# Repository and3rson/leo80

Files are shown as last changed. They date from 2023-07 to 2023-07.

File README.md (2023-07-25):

# leo80
Z80-based single-board computer

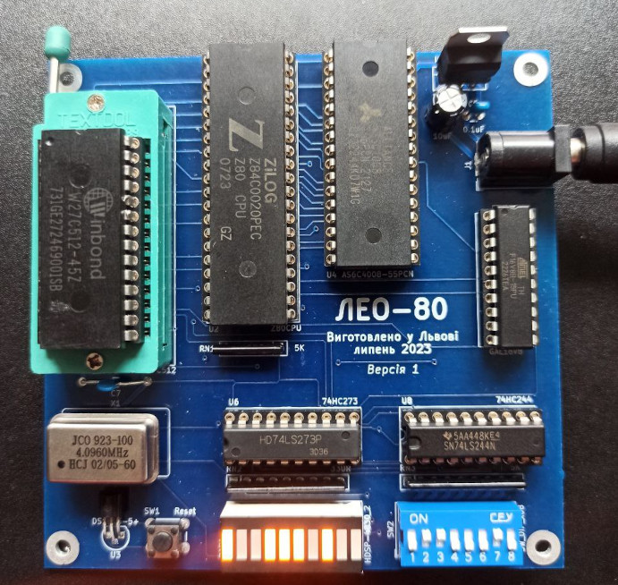
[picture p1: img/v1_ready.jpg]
Assembled device


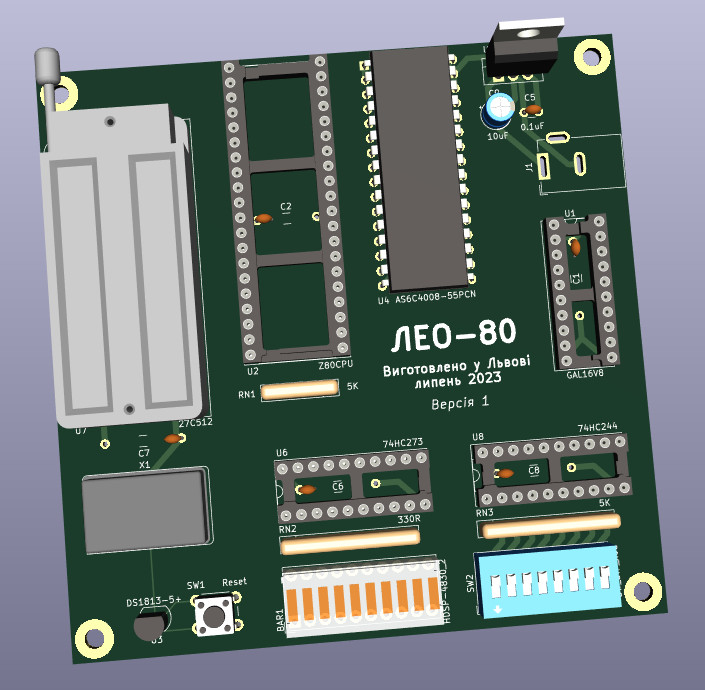
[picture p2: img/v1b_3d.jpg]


# Design considerations

- $0000-$7FFF - ROM.
- $8000-$FFFF - RAM.
- Address decoding with ATF16V8.
- Using perfboard for this, so trying to keep it small & simple - will be adding more fancy things later (LCD, UART, etc).
- Simple 8-bit input through '244 tri-state buffer.
- Simple 8-bit output through '273 flip-flop with 8 LEDs for visual output.
- I used AS6C4008 in schematic since it's included in Kicad parts by default. I have various SRAM chips available. Same with W27C512 EPROM.

# Schematic

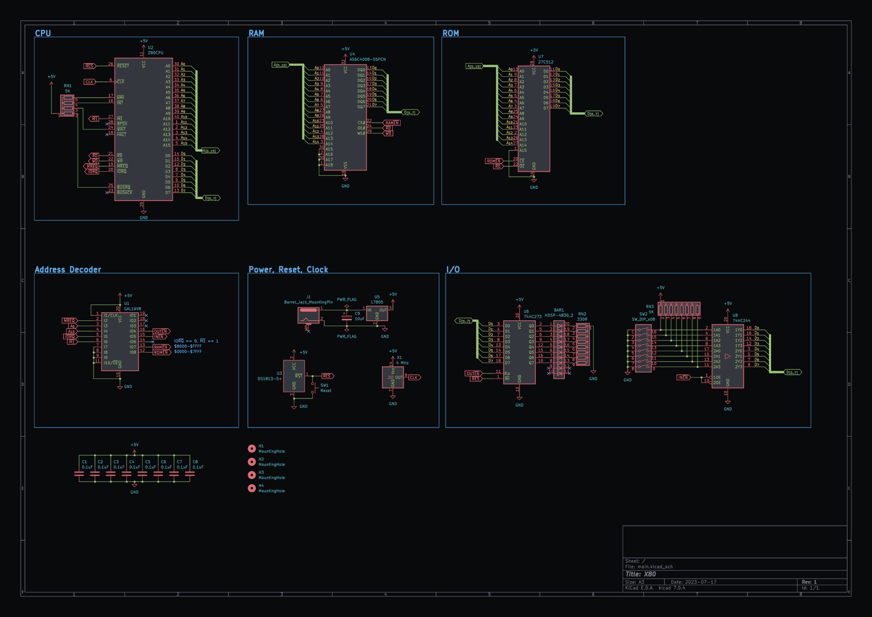
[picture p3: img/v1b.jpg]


# PCB

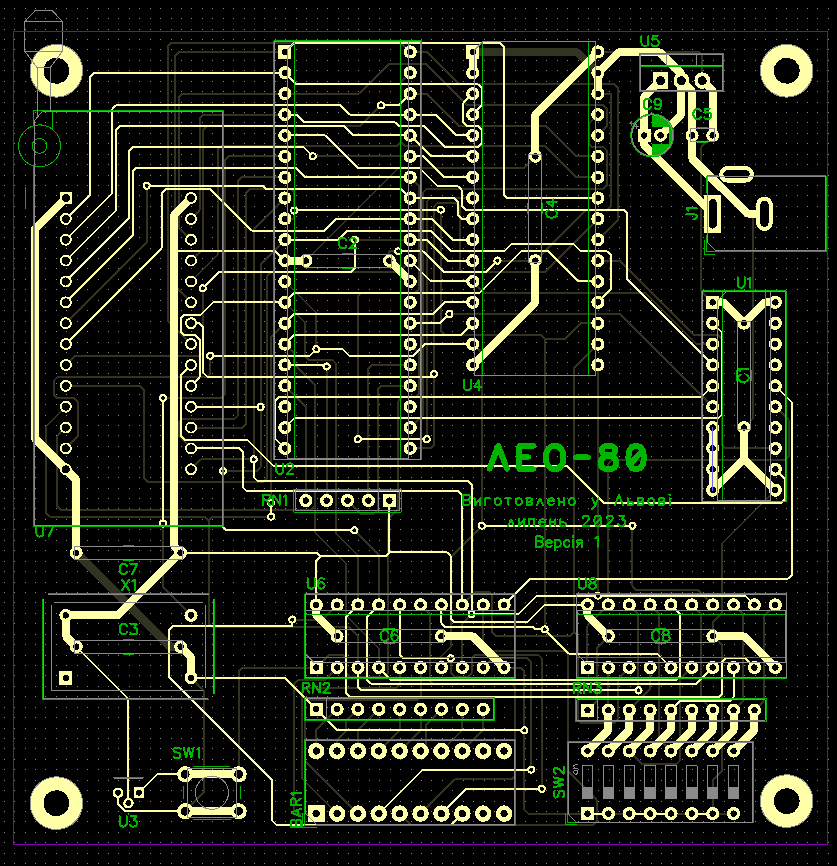
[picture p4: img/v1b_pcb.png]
PCB


# Resources

- anycpu.org forum [thread](https://anycpu.org/forum/viewtopic.php?f=25&t=1060)
- Original [datasheet](https://www.zilog.com/docs/z80/um0080.pdf) (very slow download), or alternatively - archived versions on [my website](https://dun.ai/files/z80.pdf) and [archive.org](https://archive.org/details/um0080httpswww.zilog.comdocsz80um0080.pdf).
- Z80 interrupt vectors: https://www.smspower.org/Development/InterruptVectors
- SjASMPlus docs: https://z00m128.github.io/sjasmplus/documentation.html

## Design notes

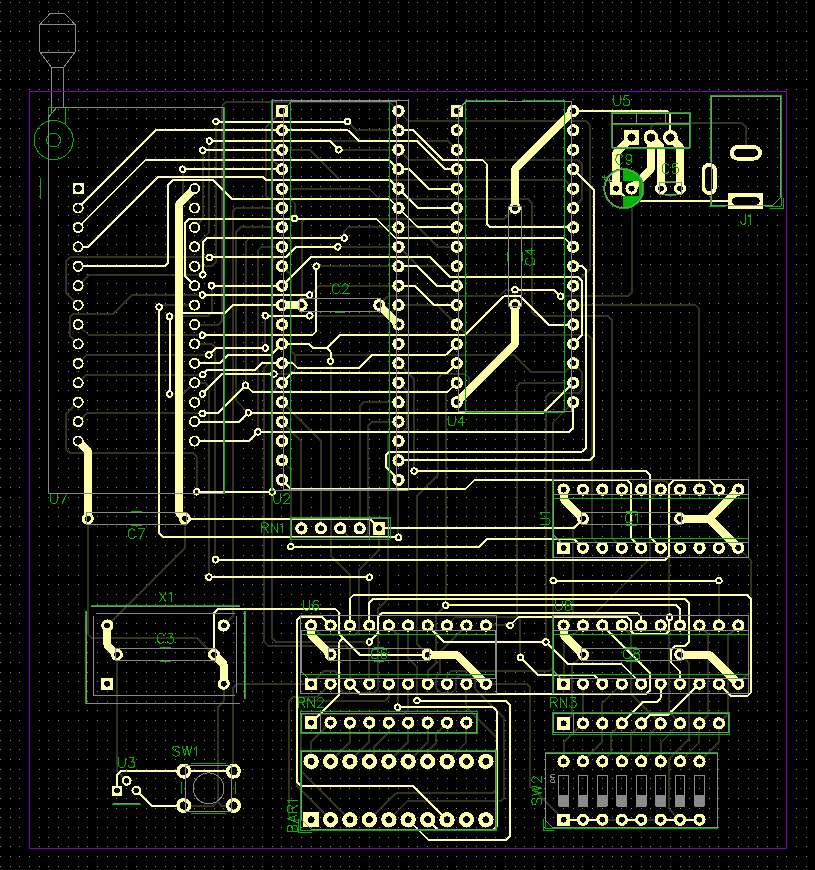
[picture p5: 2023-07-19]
img/v1a_pcb.png

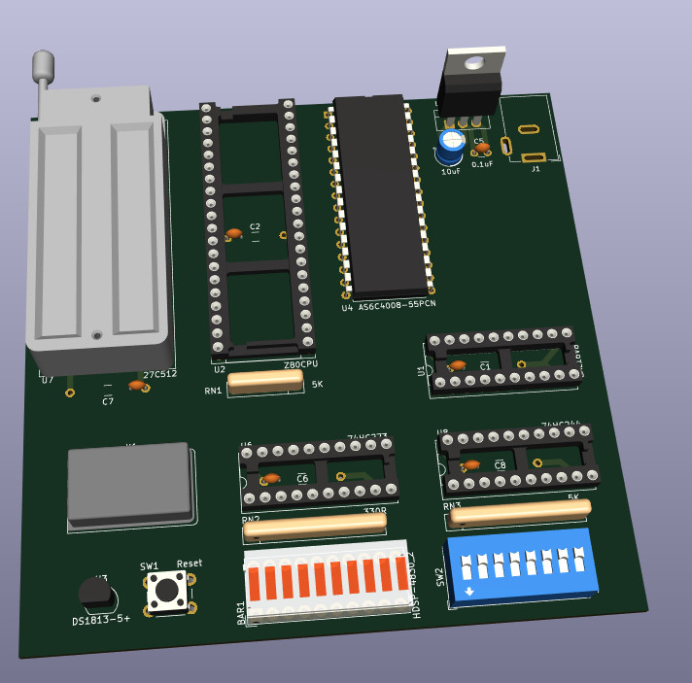
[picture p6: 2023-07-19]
img/v1a_3d.jpg

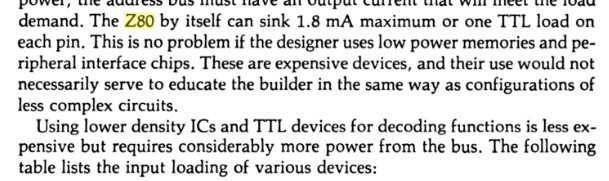
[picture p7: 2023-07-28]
img/bus_excerpt.jpg

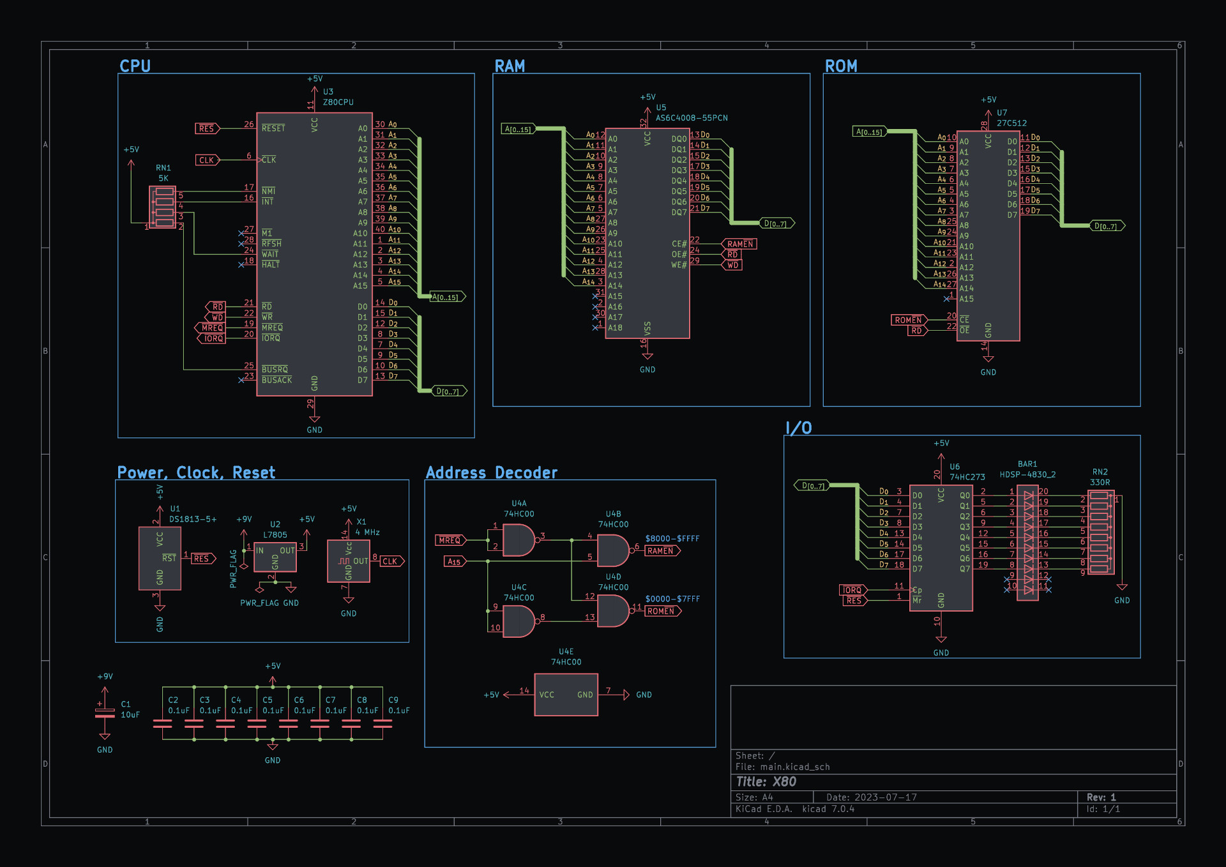
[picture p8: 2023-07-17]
img/v1.jpg

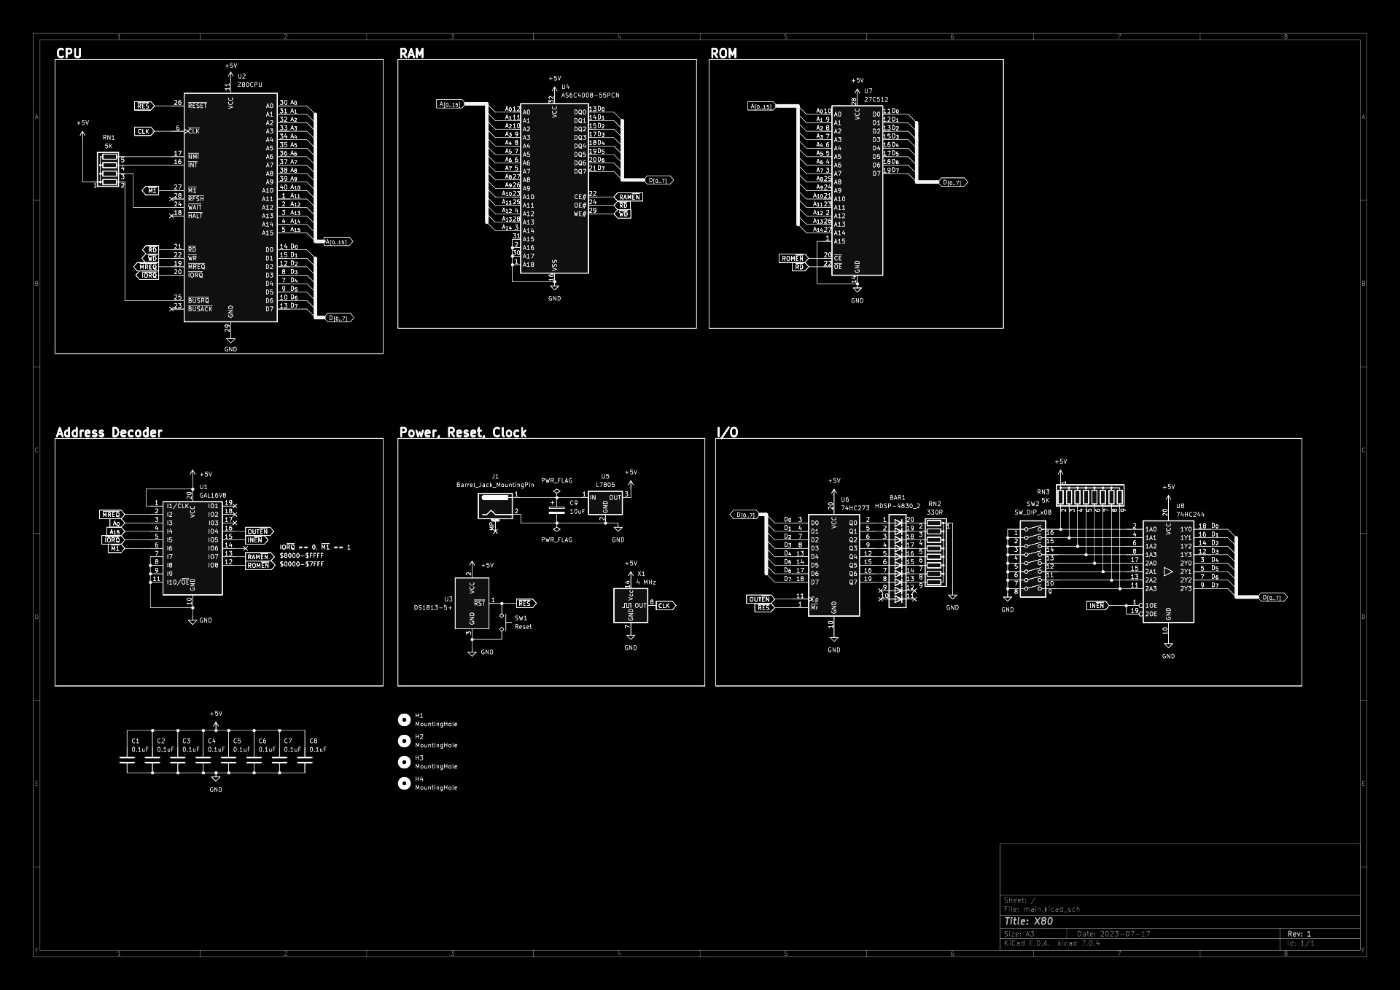
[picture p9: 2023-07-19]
img/v1b_bw.jpg

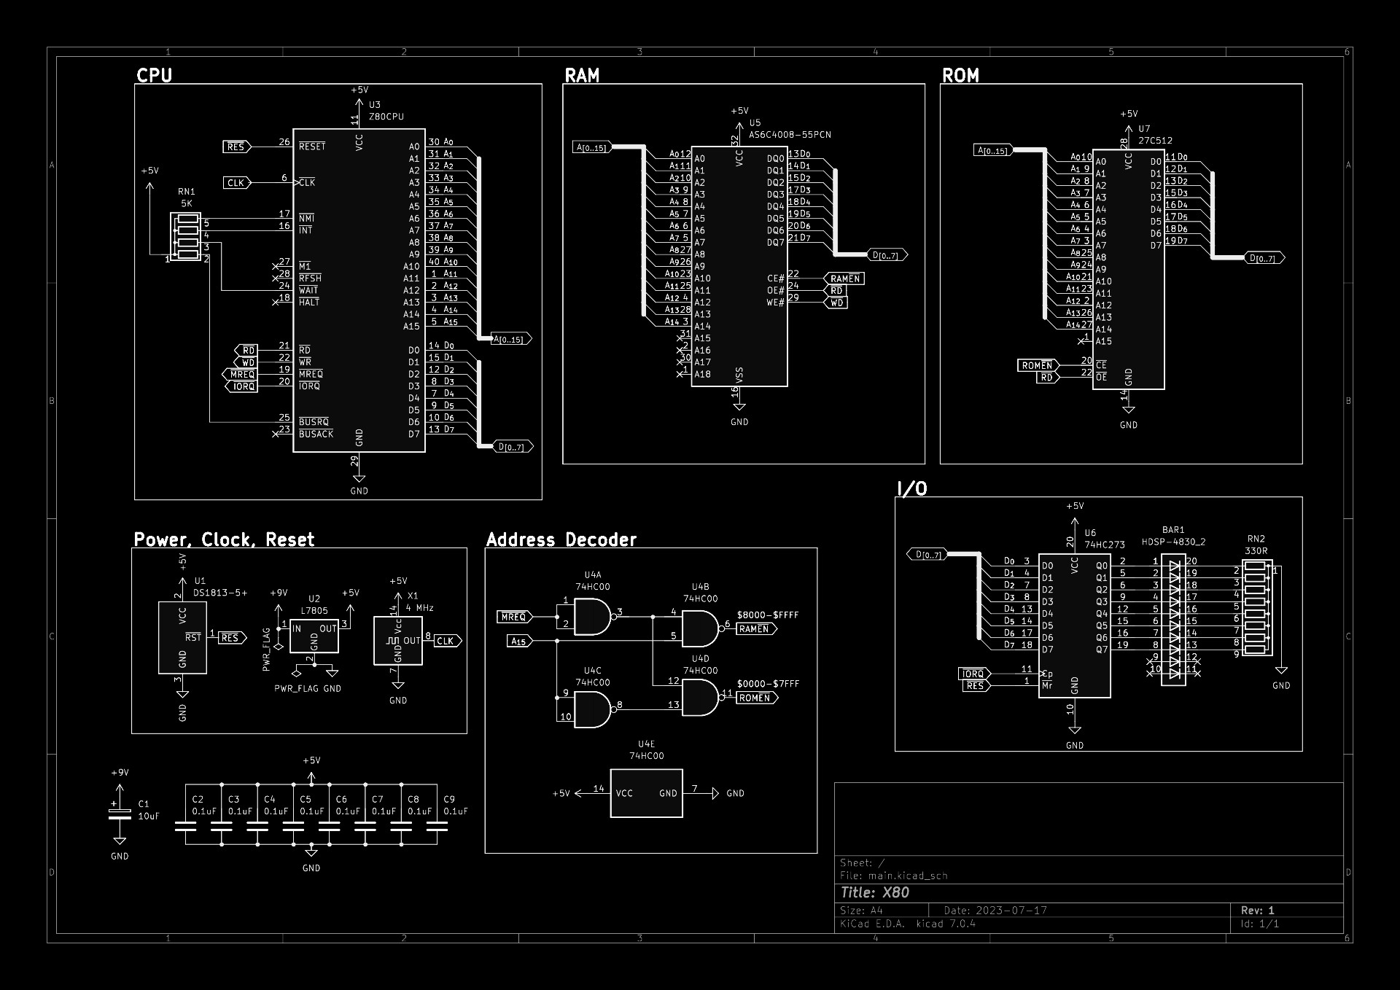
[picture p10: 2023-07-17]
img/v1_bw.jpg

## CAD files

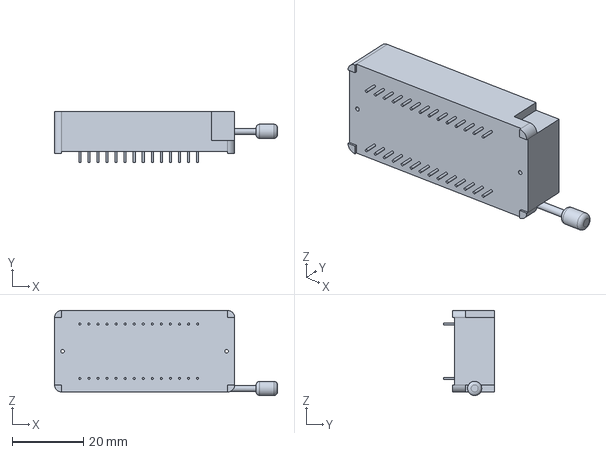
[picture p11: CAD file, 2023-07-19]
kicad/main/3dmodels/28ZIF_PlaceHolderRevB.stp
62.5 x 14.2 x 23.9 mm

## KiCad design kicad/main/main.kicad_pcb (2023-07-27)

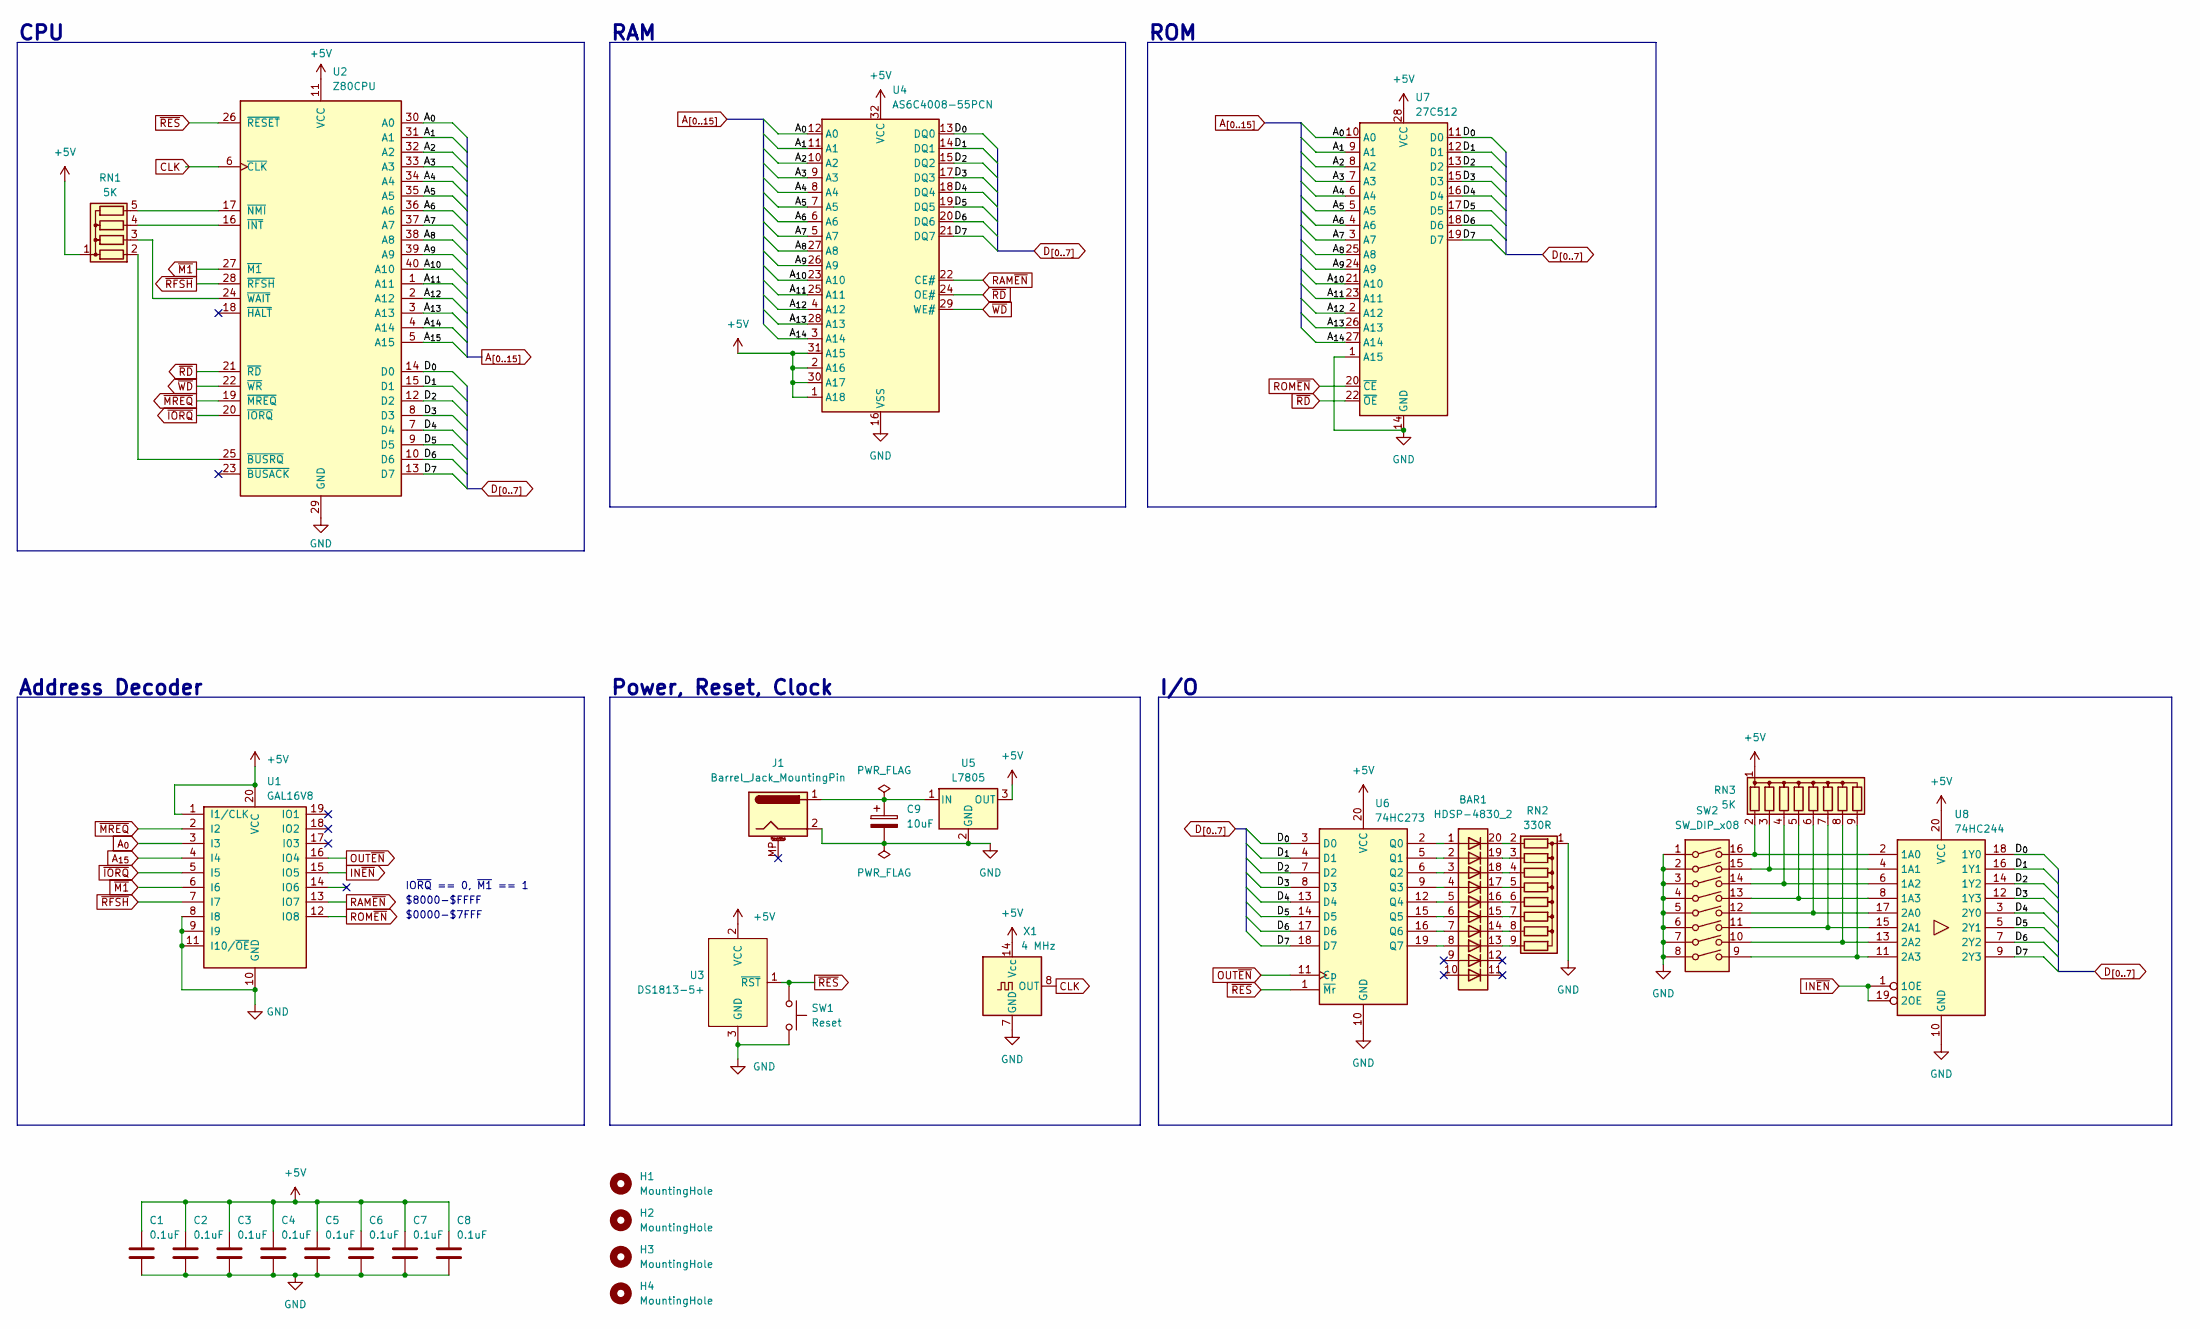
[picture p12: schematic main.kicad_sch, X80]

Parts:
BAR1: HDSP-4830_2; HDSP-4830
C1, C3, C4, C6, C7, C8: 0.1uF; C_Disc_Long
C2: 0.1uF; C_Disc_Medium
C5: 0.1uF; C_Disc_D3.0mm_W1.6mm_P2.50mm
C9: 10uF; CP_Radial_D5.0mm_P2.00mm
H1, H2, H3, H4: MountingHole; MountingHole_3.2mm_M3_Pad
J1: Barrel_Jack_MountingPin; BarrelJack_GCT_DCJ200-10-A_Horizontal
RN1: 5K; R_Array_SIP5
RN2: 330R; R_Array_SIP9
RN3: 5K; R_Array_SIP9
SW1: Reset; SW_PUSH_6mm
SW2: SW_DIP_x08; SW_DIP_SPSTx08_Slide_9.78x22.5mm_W7.62mm_P2.54mm
U1: GAL16V8; DIP-20_W7.62mm_Socket
U2: Z80CPU; DIP-40_W15.24mm_Socket
U3: DS1813-5+; TO-92
U4: AS6C4008-55PCN; DIP-32_W15.24mm
U5: L7805; TO-220-3_Vertical
U6: 74HC273; DIP-20_W7.62mm_Socket
U7: 27C512; ZIF28
U8: 74HC244; DIP-20_W7.62mm_Socket
X1: 4 MHz; Oscillator_DIP-14

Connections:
+5V: C1.1, C2.1, C3.1, C4.1, C5.1, C6.1, C7.1, C8.1, RN1.1 (common), RN3.1 (common), U1.1 (I1/CLK), U1.20 (VCC), U2.11 (VCC), U3.2 (VCC), U4.1 (A18), U4.2 (A16), U4.30 (A17), U4.31 (A15), U4.32 (VCC), U5.3 (OUT), U6.20 (VCC), U7.28 (VCC), U8.20 (VCC), X1.14 (Vcc)
A_{0}: U1.3 (I3), U2.30 (A0), U4.12 (A0), U7.10 (A0)
A_{1}: U2.31 (A1), U4.11 (A1), U7.9 (A1)
A_{2}: U2.32 (A2), U4.10 (A2), U7.8 (A2)
A_{3}: U2.33 (A3), U4.9 (A3), U7.7 (A3)
A_{4}: U2.34 (A4), U4.8 (A4), U7.6 (A4)
A_{5}: U2.35 (A5), U4.7 (A5), U7.5 (A5)
A_{6}: U2.36 (A6), U4.6 (A6), U7.4 (A6)
A_{7}: U2.37 (A7), U4.5 (A7), U7.3 (A7)
A_{8}: U2.38 (A8), U4.27 (A8), U7.25 (A8)
A_{9}: U2.39 (A9), U4.26 (A9), U7.24 (A9)
A_{10}: U2.40 (A10), U4.23 (A10), U7.21 (A10)
A_{11}: U2.1 (A11), U4.25 (A11), U7.23 (A11)
A_{12}: U2.2 (A12), U4.4 (A12), U7.2 (A12)
A_{13}: U2.3 (A13), U4.28 (A13), U7.26 (A13)
A_{14}: U2.4 (A14), U4.3 (A14), U7.27 (A14)
A_{15}: U1.4 (I4), U2.5 (A15)
CLK: U2.6 (~CLK), X1.8 (OUT)
D_{0}: U2.14 (D0), U4.13 (DQ0), U6.3 (D0), U7.11 (D0), U8.18 (1Y0)
D_{1}: U2.15 (D1), U4.14 (DQ1), U6.4 (D1), U7.12 (D1), U8.16 (1Y1)
D_{2}: U2.12 (D2), U4.15 (DQ2), U6.7 (D2), U7.13 (D2), U8.14 (1Y2)
D_{3}: U2.8 (D3), U4.17 (DQ3), U6.8 (D3), U7.15 (D3), U8.12 (1Y3)
D_{4}: U2.7 (D4), U4.18 (DQ4), U6.13 (D4), U7.16 (D4), U8.3 (2Y0)
D_{5}: U2.9 (D5), U4.19 (DQ5), U6.14 (D5), U7.17 (D5), U8.5 (2Y1)
D_{6}: U2.10 (D6), U4.20 (DQ6), U6.17 (D6), U7.18 (D6), U8.7 (2Y2)
D_{7}: U2.13 (D7), U4.21 (DQ7), U6.18 (D7), U7.19 (D7), U8.9 (2Y3)
GND: C1.2, C2.2, C3.2, C4.2, C5.2, C6.2, C7.2, C8.2, C9.2, J1.2, RN2.1 (common), SW1.2, SW2.1, SW2.2, SW2.3, SW2.4, SW2.5, SW2.6, SW2.7, SW2.8, U1.8 (I8), U1.9 (I9), U1.10 (GND), U1.11 (I10/~OE), U2.29 (GND), U3.3 (GND), U4.16 (VSS), U5.2 (GND), U6.10 (GND), U7.1 (A15), U7.14 (GND), U8.10 (GND), X1.7 (GND)
IN~EN: U1.15 (IO5), U8.1 (1OE), U8.19 (2OE)
unnamed: RN1.2 (R1), U2.25 (~BUSRQ)
unnamed: RN1.3 (R2), U2.24 (~WAIT)
unnamed: RN1.4 (R3), U2.16 (~INT)
unnamed: RN1.5 (R4), U2.17 (~NMI)
unnamed: BAR1.20 (K), RN2.2 (R1)
unnamed: BAR1.19 (K), RN2.3 (R2)
unnamed: BAR1.18 (K), RN2.4 (R3)
unnamed: BAR1.17 (K), RN2.5 (R4)
unnamed: BAR1.16 (K), RN2.6 (R5)
unnamed: BAR1.15 (K), RN2.7 (R6)
unnamed: BAR1.14 (K), RN2.8 (R7)
unnamed: BAR1.13 (K), RN2.9 (R8)
unnamed: RN3.2 (R1), SW2.16, U8.2 (1A0)
unnamed: RN3.3 (R2), SW2.15, U8.4 (1A1)
unnamed: RN3.4 (R3), SW2.14, U8.6 (1A2)
unnamed: RN3.5 (R4), SW2.13, U8.8 (1A3)
unnamed: RN3.6 (R5), SW2.12, U8.17 (2A0)
unnamed: RN3.7 (R6), SW2.11, U8.15 (2A1)
unnamed: RN3.8 (R7), SW2.10, U8.13 (2A2)
unnamed: RN3.9 (R8), SW2.9, U8.11 (2A3)
unnamed: C9.1, J1.1, U5.1 (IN)
unnamed: BAR1.1 (A), U6.2 (Q0)
unnamed: BAR1.2 (A), U6.5 (Q1)
unnamed: BAR1.3 (A), U6.6 (Q2)
unnamed: BAR1.4 (A), U6.9 (Q3)
unnamed: BAR1.5 (A), U6.12 (Q4)
unnamed: BAR1.6 (A), U6.15 (Q5)
unnamed: BAR1.7 (A), U6.16 (Q6)
unnamed: BAR1.8 (A), U6.19 (Q7)
OUT~EN: U1.16 (IO4), U6.11 (Cp)
RAM~EN: U1.13 (IO7), U4.22 (CE#)
ROM~EN: U1.12 (IO8), U7.20 (~CE)
~IORQ: U1.5 (I5), U2.20 (~IORQ)
~M1: U1.6 (I6), U2.27 (~M1)
~MREQ: U1.2 (I2), U2.19 (~MREQ)
~RD: U2.21 (~RD), U4.24 (OE#), U7.22 (~OE)
~RES: SW1.1, U2.26 (~RESET), U3.1 (~RST), U6.1 (~Mr)
~RFSH: U1.7 (I7), U2.28 (~RFSH)
~WD: U2.22 (~WR), U4.29 (WE#)

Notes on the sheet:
RAM
$8000-$FFFF
Power, Reset, Clock
CPU
ROM
IO~{RQ} == 0, ~{M1} == 1
$0000-$7FFF
I/O
Address Decoder

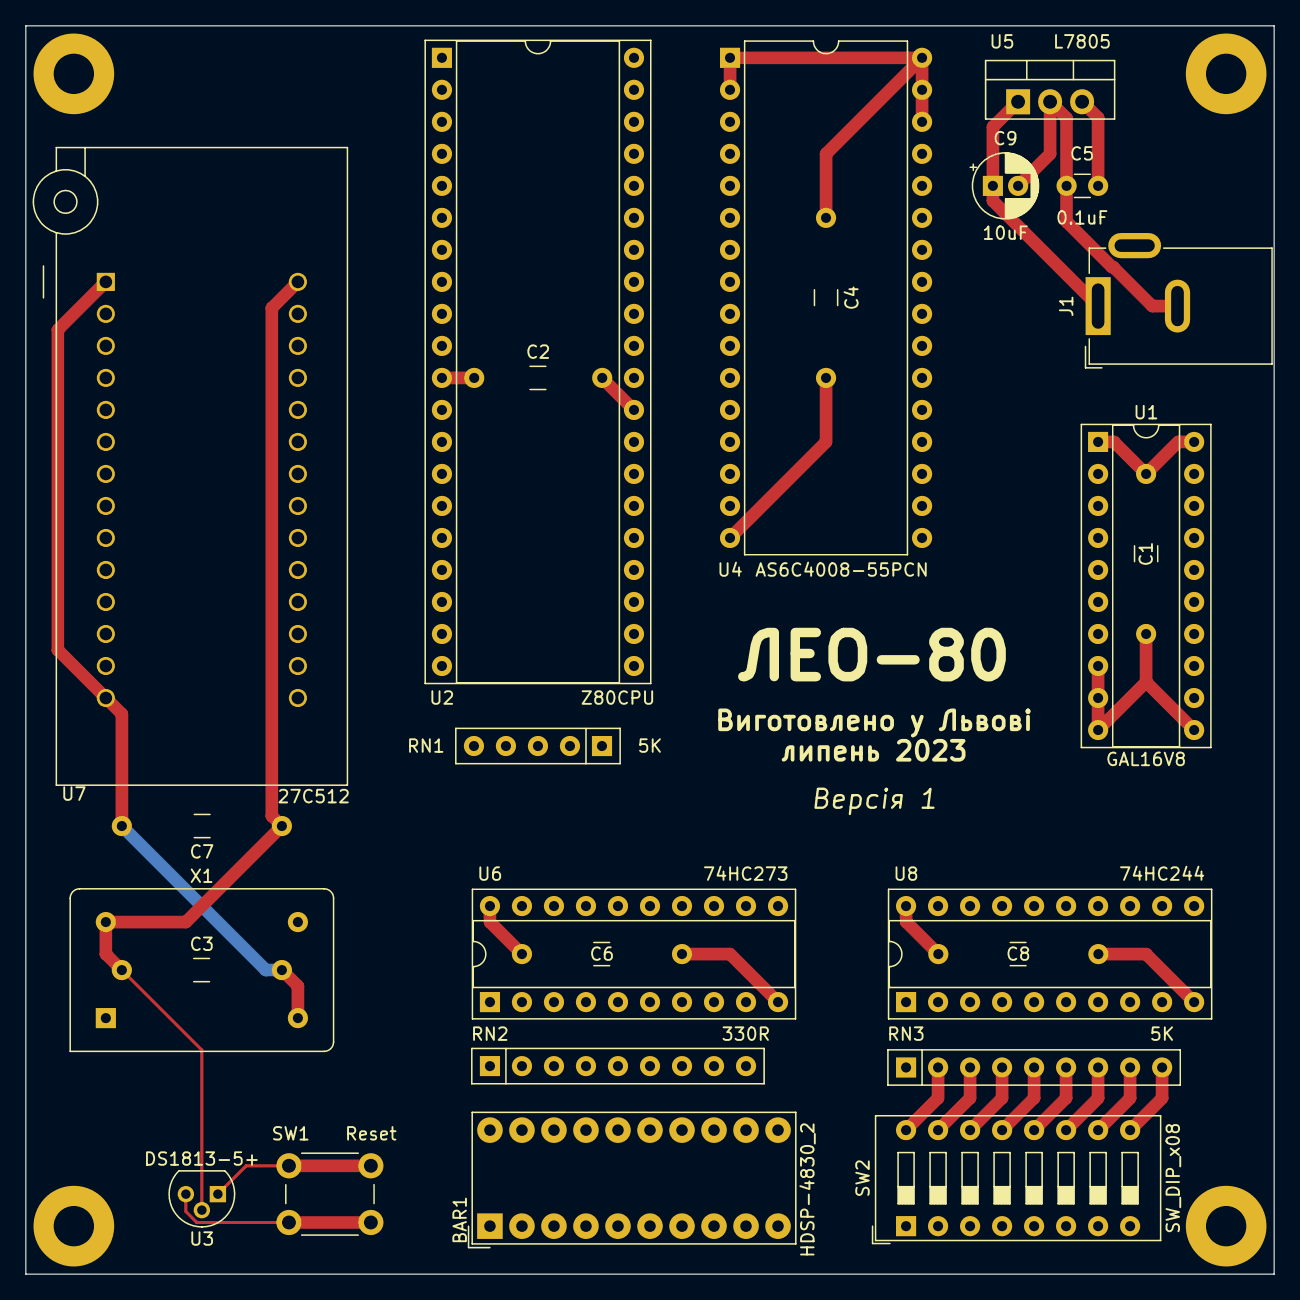
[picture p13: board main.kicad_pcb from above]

Board: 2 copper layers, 99.1 x 99.1 mm, 29 parts (0 on the bottom side), 67 nets.

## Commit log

2023-07-17 Add Kicad schematic
    [main.kicad_pcb, main.kicad_sch]
2023-07-18 Smaller KiCad symbols, reset button
    [main.kicad_pcb, main.kicad_sch]
2023-07-19 Basic PCB
    [main.kicad_pcb, main.kicad_sch]
2023-07-19 First PCB
    [28ZIF_PlaceHolderRevB.stp, backup.kicad_sch, main.kicad_pcb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]
2023-07-19 PCB update + Gerber
    [Board.gbr, Bot.gbr, BotAssembly.gbr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]
2023-07-19 Final v1 PCB
    [1 - Top.gbr, 2 - Bot.gbr, BoardOutline.gbr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]
2023-07-22 Add sample program (main)
2023-07-27 Fix RAM CE2, add /RFSH
    [main.kicad_pcb, main.kicad_sch]
